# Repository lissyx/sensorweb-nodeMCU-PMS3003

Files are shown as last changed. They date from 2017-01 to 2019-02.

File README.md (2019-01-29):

NodeMCU PMS3003 PM2.5 Sensor
============================

This repo aims at providing a PM2.5 (and others) sensor that pushes data to the
Internets, namely AirCasting API. It uses a PMS3003 + NodeMCU v1.0 (ESP-12E), as
it was built as a side-project to augment (now defunct) Mozilla SensorWeb
project with something that could be autonomous and outdoor.

Good Known Setup
================
 - Arduino IDE 1.8.8
 - ESP8266 Package v2.4.2
 - ArduinoJson v5.13.5
 - NtpClientLib v2.5.1
 - Time v1.5
 - WiFiManager v0.14
 - ESP8266TrueRandom (any version?)
 - ESP8266FS.jar v0.3.0 (not a lib, need to be installed separately into tools/
   arduino subdir)

Ensure to configure board in Arduino IDE as:
 - NodeMCU 1.0 (ESP-12E)
 - 80MHz
 - Flash
 - 4M (3M SPIFFS)
 - v2 Lower Memory

Configuration
=============
For first flash, ensure you properly populate `data/` subdirectory with:
 - `wifi.json`
 - `ntp.json`
 - `aircasting.json`
Please follow the templates named <FILE>.in, copy them as the proper name under
`data/`. Then in Arduino IDE, flash using `Tools`, `ESP8266 Sketch Data Upload`.

Default configuration should be for AirCasting.org website, but it is expected
to work on any instance following their API.

Then you can build and flash. It should boot and work.

Debugging
=========
Serial debugging should work over USB. The same data is sent over the wire,
defaulting to UDP multicast address `239.0.0.1`, port `8899`.

Outdooring
==========
To be able to handle outdoor, original SensorWeb project has been augmented with
a power source. This leads to the design of a small PCB that serves several
purposes:
 - properly fitting / holding the NodeMCU with inline connectors
 - some logic to handle PMS3003 standby mode
 - proper connector for the PMS3003 wired to the NodeMCU pins
 - proper 5v: PMS3003 tends to be picky, working with less than 4v but giving
   inconsistent results

The power part of the PCB is inspired from Adafruit's Minty Boost:
https://learn.adafruit.com/minty-boost/overview

Solar power cannot be available 100% of the time, so it is battery-backed, using
the kit provided by Adafruit:
https://learn.adafruit.com/usb-dc-and-solar-lipoly-charger?view=all

Solar panel are also provided, though they can be found at a lot of different
places.

Any LiPo or LiIon should work.

Checkout the Kicad project for exact references.

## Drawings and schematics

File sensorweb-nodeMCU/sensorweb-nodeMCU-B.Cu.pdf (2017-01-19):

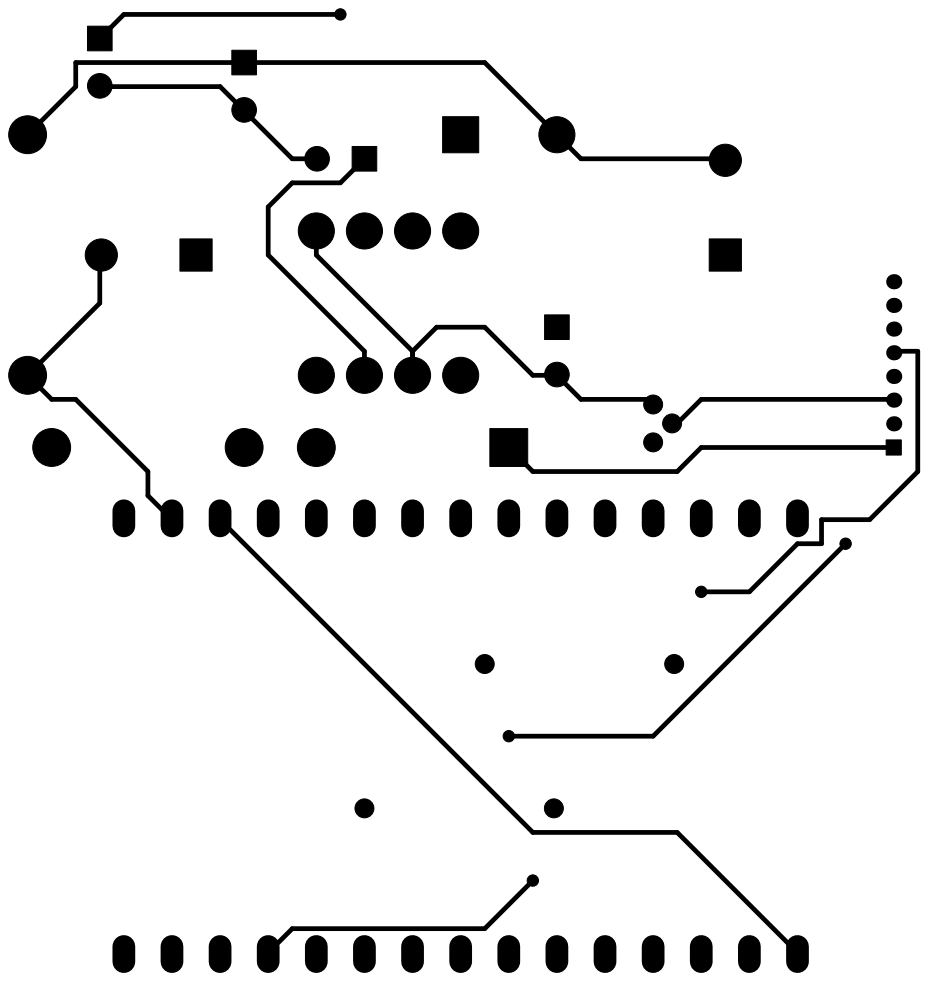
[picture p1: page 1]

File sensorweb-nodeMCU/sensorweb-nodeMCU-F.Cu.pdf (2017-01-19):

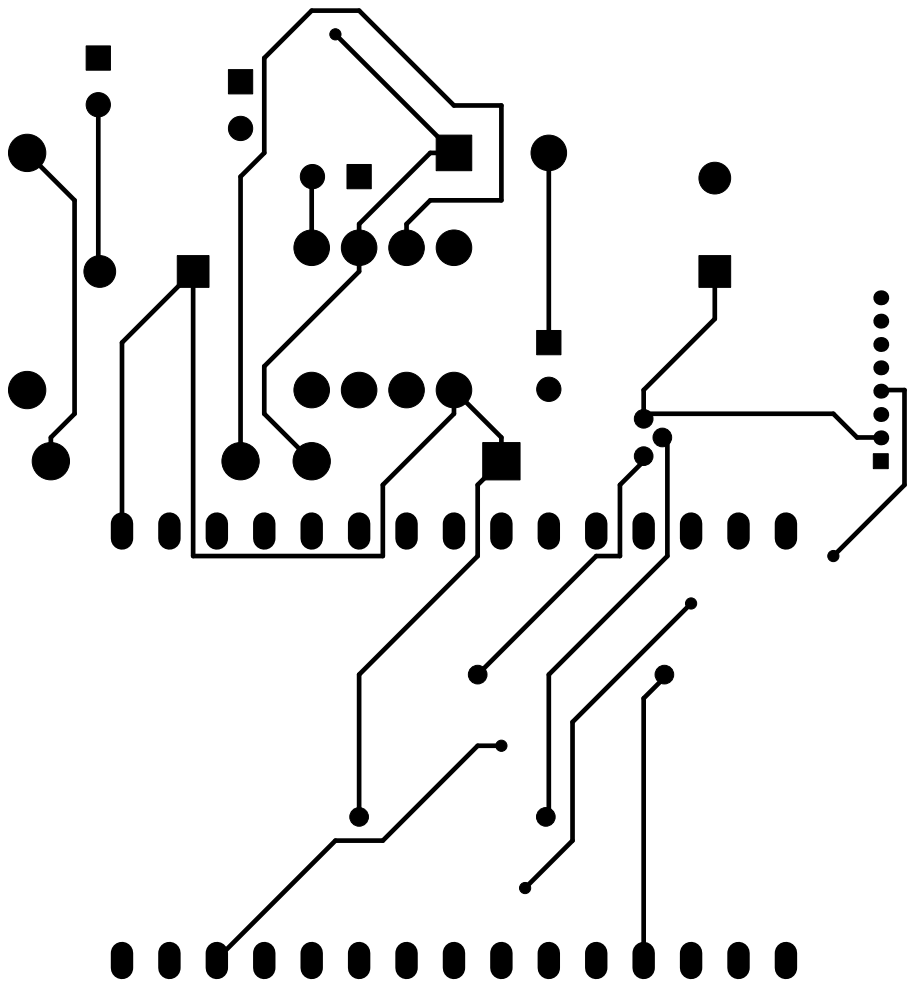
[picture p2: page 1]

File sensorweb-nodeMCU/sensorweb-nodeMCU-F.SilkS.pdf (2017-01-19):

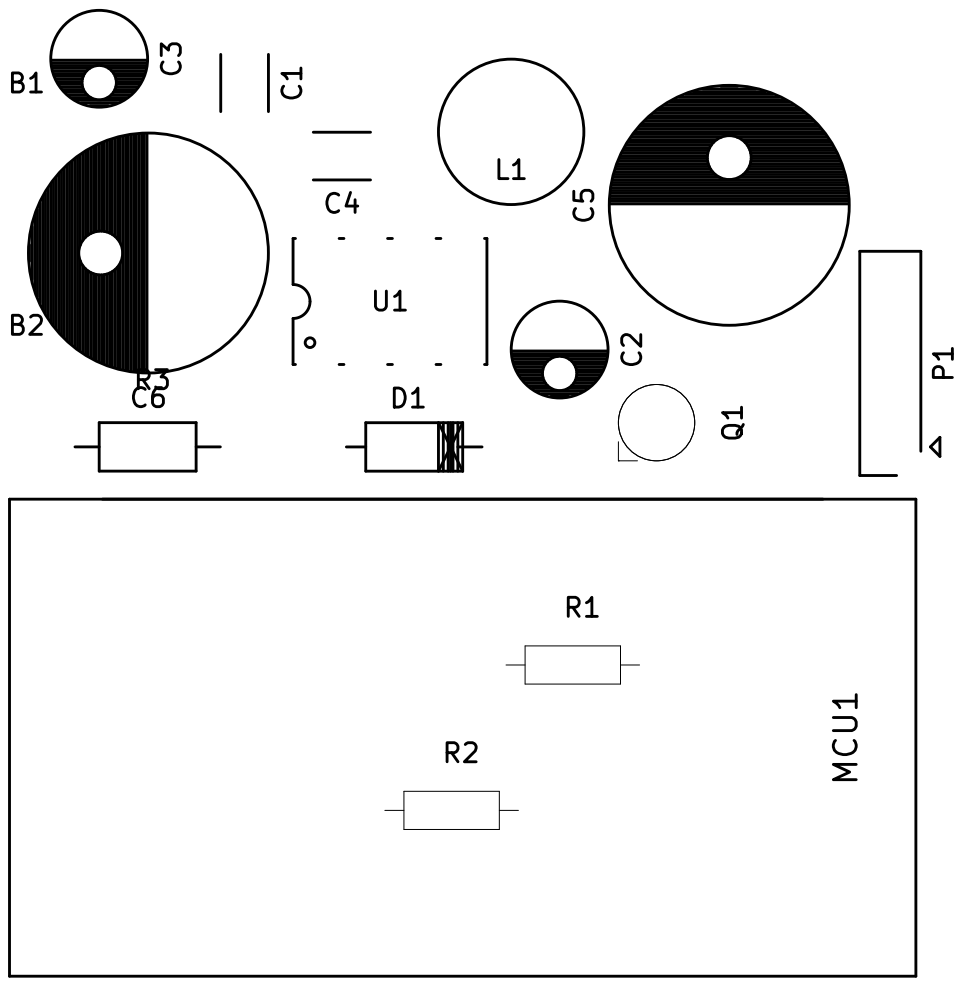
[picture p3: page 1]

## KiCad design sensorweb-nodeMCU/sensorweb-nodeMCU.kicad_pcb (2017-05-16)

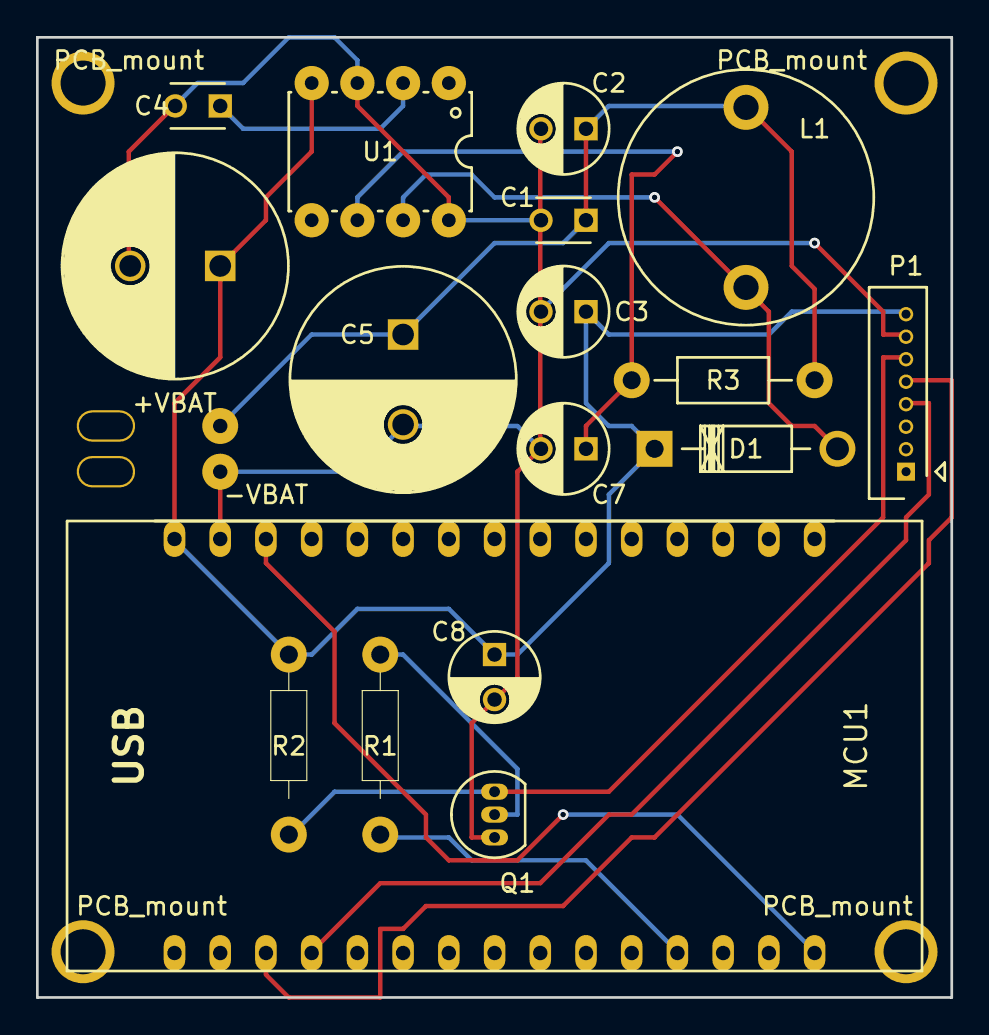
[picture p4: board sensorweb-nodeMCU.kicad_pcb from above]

Board: 2 copper layers, 50.8 x 53.3 mm, 19 parts (0 on the bottom side), 12 nets.

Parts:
+VBAT: +VBAT; SolderWirePad_single_0-8mmDrill
-VBAT: -VBAT; SolderWirePad_single_0-8mmDrill
C1, C4: 0.1µF; C_Disc_D3_P2.5
C2, C3, C8: 220µF; C_Radial_D5_L6_P2.5
C5, C6: 4700µF; C_Radial_D12.5_L25_P5
C7: 1µF; C_Radial_D5_L6_P2.5
D1: 1N5817; Diode_DO-41_SOD81_Horizontal_RM10
L1: 22µH; Neosid_Inductor_Sd14
MCU1: NodeMCU-1.0; nodemcu
P1: PMS3003; Molex_PicoBlade_53047-0810
Q1: 2N2222; TO-92_Inline_Narrow_Oval
R1, R2: 10k; Resistor_Horizontal_RM10mm
R3: 2ohm / 10ohm; Resistor_Horizontal_RM10mm
U1: LT1302CN8-5; PDIP-8

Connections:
+5V: C3.1, C6.1, C8.1, D1.1, MCU1.15, P1.8, R2.1, U1.4
GND: -VBAT.1, C1.2, C2.2, C3.2, C4.2, C5.2, C6.2, C7.2, C8.2, MCU1.14, P1.7, Q1.1, U1.3, U1.8
unnamed: +VBAT.1, C1.1, C2.1, C5.1, L1.2, R3.1
unnamed: C4.1, U1.2
unnamed: C7.1, R3.2, U1.6
unnamed: D1.2, L1.1, U1.7
unnamed: MCU1.13, MCU1.30
unnamed: MCU1.18, P1.5
unnamed: MCU1.19, P1.4
unnamed: MCU1.27, R1.2
unnamed: P1.6, Q1.3, R2.2
unnamed: Q1.2, R1.1

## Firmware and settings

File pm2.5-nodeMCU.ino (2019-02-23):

#include <Arduino.h>

#include <ESP8266WiFi.h>
#include <ESP8266WiFiMulti.h>
#include <ESP8266HTTPClient.h>

#include <ArduinoJson.h>
#include <FS.h>
#include <NtpClientLib.h>
#include <WiFiUdp.h>

uint32 pm1   = UINT32_MAX;
uint32 pm2_5 = UINT32_MAX;
uint32 pm10  = UINT32_MAX;

unsigned int sleepWakeCycles = 0;
unsigned long rtcSystemTime  = 0;
unsigned long startupMillis = 0;

#include "debug.h"
#include "config.h"
#include "LEDs.h"
#include "PMS3003.h"
// #include "SensorWeb.h"

// used by date_ISO8601() in utils.h
#include "utils.h"

#include "AirCasting.h"
#include "RTC.h"

bool ntpInitialSync = false;
bool readyForNTP = false;
bool ntpRunning = false;
unsigned int ntpErrors = 0;
double ntpStartTime = 0;
double ntpWaitTime  = 0;
ESP8266WiFiMulti* WiFiMulti;

void ntpSyncEventHandler(NTPSyncEvent_t error) {
  if (!ntpRunning) {
    serialUdpDebug("NTPSyncEvent: Ignoring stale event, expected with dayLight=true");
    /**
     * 23:07:52.019 -> NTPSyncEvent: Stale event, expected with dayLight=true
     * 23:07:52.085 -> NTPSyncEvent: 07:28:16 07/02/2036
     * 23:07:52.119 -> NTPSyncEvent: actualRuntime=2.27 -- bootTime=325
     * 23:07:52.152 -> NTPSyncEvent: actualSystemTime=2036-02-07T07:28:16.000+01:00 -- expectedSystemTime=2019-01-29T23:08:08.000+01:00
     * 23:07:52.285 -> NTPSyncEvent: deltaTime=-537178804.94200 => slowDownFactor=-1790595.01647
     */
    return;
  }

  ntpRunning = false;

  if (error) {
    ntpErrors += 1;
    if (error == noResponse) {
      serialUdpDebug("NTPSyncEvent: server not reachable");
    } else if (error == invalidAddress) {
      serialUdpDebug("NTPSyncEvent: invalid server address");
    } else {
      serialUdpDebug("NTPSyncEvent: " + String(error));
    }
  } else {
    ntpErrors = 0;
    serialUdpDebug("NTPSyncEvent: " + NTP.getTimeDateString(NTP.getLastNTPSync()));
    if (!ntpInitialSync) {
      // serialUdpDebug("NTPSyncEvent: set ntpInitialSync");
      ntpInitialSync = true;
    }

    ntpWaitTime = millis() - ntpStartTime;

    // If we receive a ntpSyncEvent for sleepWakeCycles=1 then we
    // are there to compute slowdown factor.
    if (sleepWakeCycles == sleepWakeCyclesSlowDownCompute) {
      double actualSystemTime   = NTP.getLastNTPSync();
      double actualRuntime      = getCurrentExecutionTime();
      double expectedSystemTime = rtcSystemTime + actualRuntime;
      double deltaTime = expectedSystemTime - actualSystemTime + (bootTime / 1000.0) + (ntpWaitTime / 1000.0);
      slowDownFactor = 1.0 + (deltaTime / execInterval);

      serialUdpDebug("NTPSyncEvent: actualRuntime=" + String(actualRuntime) + " -- bootTime=" + String(bootTime));
      serialUdpDebug("NTPSyncEvent: actualSystemTime=" + date_ISO8601(actualSystemTime) + " -- expectedSystemTime=" + date_ISO8601(expectedSystemTime));
      serialUdpDebug("NTPSyncEvent: deltaTime=" + String(deltaTime, 5) + " => slowDownFactor=" + String(slowDownFactor, 5));
    }
  }
}

void startNtp() {
  if (!ntpRunning) {
    ntpRunning = true;
    NtpConfig* ntpConfig = NtpConfig::getInstance();
    NTP.onNTPSyncEvent(ntpSyncEventHandler);
    NTP.begin(ntpConfig->ntpServer, ntpConfig->ntpTZOffset, ntpConfig->ntpDayLight);
    NTP.setInterval(ntpFirstSync, ntpInterval);
    serialUdpIntDebug("NTP: NTP.begin(" + ntpConfig->ntpServer + ", " + ntpConfig->ntpTZOffset + ", " + ntpConfig->ntpDayLight + ")");
    ntpStartTime = millis();
  } else {
    serialUdpIntDebug("NTP: not starting because ntpRunning=true");
  }
}

void stopNtp() {
  ntpRunning = false;
  NTP.stop();
}

void wifiHasIpAddress(WiFiEventStationModeGotIP evt) {
  serialUdpIntDebug("UP: " + VERSION + ":" + (BUILD_DATE + " " + BUILD_TIME) + "@" + evt.ip.toString());

  // Only schedule NTP sync when we do need it.
  if (sleepWakeCycles <= sleepWakeCyclesSlowDownCompute) {
    readyForNTP = true;
  }
}

void wifiConnected(WiFiEventStationModeConnected evt) {
  serialUdpIntDebug("Connected to SSID: " + evt.ssid);
}

void wifiDisconnected(WiFiEventStationModeDisconnected evt) {
  DEBUG_SERIAL("Disconnected from SSID: " + evt.ssid + "; reason: " + evt.reason);
  DEBUG_SERIAL("Reason: " + evt.reason);

  readyForNTP = false;

  if (sleepWakeCycles <= sleepWakeCyclesSlowDownCompute) {
    stopNtp();
  }
}

void setup() {
  static WiFiEventHandler connectEvent, hasIpEvent, disconnectEvent;

  startupMillis = millis();

  WiFi.persistent(true);
  WiFi.mode(WIFI_STA);

  // Measure how much power we can save there ...
  // According to ESP docs:
  // 802.11b: TX ~170mA, RX ~50mA
  // 802.11g: TX ~140mA, RX ~56mA
  // 802.11n: TX ~120mA, RX ~56mA
  WiFi.setPhyMode(WIFI_PHY_MODE_11N);

  const rst_info * resetInfo = system_get_rst_info();
  if (resetInfo->reason == REASON_DEEP_SLEEP_AWAKE) {
    if (readTimeFromRTC()) {
      // If we wake up from deep sleep AND sleepWakeCycles is one
      // it means we did a first NTP sync. Let's do a second one.
      if (sleepWakeCycles < forceResync) {
        if (sleepWakeCycles > sleepWakeCyclesSlowDownCompute) {
          ntpInitialSync  = true;
        }
      } else {
        sleepWakeCycles = 0;
        slowDownFactor  = 1.0;
      }
    }
  }

  // Reconfigure watchdog at least twice expected secs.
  ESP.wdtEnable(30 * 1000);

  PM_SERIAL.begin(9600);
  DEBUG_SERIAL("Booting ...");

#if LWIP_IPV6
  DEBUG_SERIAL("IPV6 is enabled\n");
#else
  DEBUG_SERIAL("IPV6 is not enabled\n");
#endif

  configure_leds();
  configure_pms3003_pin();

  // put PMS3003 into standby for now
  power_pms3003(false);

  hasIpEvent      = WiFi.onStationModeGotIP(wifiHasIpAddress);
  connectEvent    = WiFi.onStationModeConnected(wifiConnected);
  disconnectEvent = WiFi.onStationModeDisconnected(wifiDisconnected);

  ntpRunning = false;
  NTP.stop();

  WiFiMulti = new ESP8266WiFiMulti();
  WifiConfig wifiConfig;
  for(int itCreds = 0 ; itCreds < wifiConfig.creds.size(); itCreds++ ) {
    WifiCreds c = wifiConfig.creds[itCreds];
    if (c.pass().length() > 0) {
      WiFiMulti->addAP(c.ssid().c_str(), c.pass().c_str());
      DEBUG_SERIAL("WifiConfig: Adding WiFi for protected " + c.ssid());
    } else {
      WiFiMulti->addAP(c.ssid().c_str());
      DEBUG_SERIAL("WifiConfig: Adding WiFi for open " + c.ssid());
    }
  }

  BLINK_LED_BOOT;
}

void loop() {
  // Let's take a few (extra) seconds and make sure brand new devices can connect.
  // Doing that always will cripple boot time:
  //  - with WiFiMulti->run() checking, we get IP ~7 secs after boot
  //  - without, we get IP ~2.9 secs after boot
  if (sleepWakeCycles == 0) {
    if (WiFiMulti->run() != WL_CONNECTED) {
      DEBUG_SERIAL("WifiConfig: not connected, waiting ...");
      delay(500);
      return;
    }
  }

  if (readyForNTP) {
    startNtp();
  }

  // Wait for NTP sync at least 3*45 secs
  // If we get nothing, go to sleep. Let's hope it is a transient issue.
  String timeNow = date_ISO8601(now(), false, false);
  if (!ntpInitialSync && (ntpErrors < 3)) {
    serialUdpDebug("Loop: no NTP initial sync, waiting ... sleepWakeCycles=" + String(sleepWakeCycles) + " ntpErrors=" + String(ntpErrors));
    delay(1250);
    return;
  }

  // Do not try to collect or send data if we have not received any NTP sync event.
  if (ntpErrors < 3) {
    AirCasting ac;
    String sessionUUID = ac.getSessionUUID();

    serialUdpDebug("SessionUUID: " + sessionUUID);
    serialUdpDebug("NTP: " + timeNow);

    // Read values from the PMS3003 connected sensor
    collect_pms3003_sensor();

    // Send even if value is 0 ; it just means sensor detected nothing.
    if(pm2_5 < UINT32_MAX && sessionUUID.length() > 0) {
      bool sent = ac.push(timeNow, pm2_5);
      serialUdpDebug("NTP: " + timeNow + " PM2.5: " + String(pm2_5) + " UUID:" + sessionUUID + " sent:" + sent);
    }
  } else {
    serialUdpDebug("Loop: too many NTP errors. Aborting.");
  }

  double executionTime = getCurrentExecutionTime();
  double nextInterval  = ((double)execInterval - (double)executionTime) * 1.0;

  // Ensure that we have something within range of [1; execInterval]
  nextInterval = MAX(1, MIN(nextInterval, execInterval));

  serialUdpDebug("Loop: deepSleep: nextInterval=" + String(nextInterval) +
                 "; executionTime=" + String(executionTime) +
                 " ; slowDownFactor=" + String(slowDownFactor, 5) +
                 "; deepSleep(" + String(nextInterval * slowDownFactor) + ")");

  // Write time to RTC only if we could get some valid.
  // e.g., no ntp works during first boot of the system
  // then goes to sleep writing time to RTC
  // When it wakes up it would restore time as if it was good
  // => you end up in the 1970s
  if (ntpInitialSync) {
    writeTimeToRTC(now(), nextInterval);
  }

  // with WAKE_RF_DEFAULT, deep sleep current ~8.2mA
  // with WAKE_NO_RFCAL, deep sleep current ~8.2mA
  // with WAKE_RF_DISABLED, no wifi on return from sleep, and deep sleep current ~8.2mA
  ESP.deepSleep(nextInterval * slowDownFactor * 1e6, WAKE_NO_RFCAL);

  return;
}

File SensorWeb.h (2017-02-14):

#ifndef PM25_NODEMCU_SENSORWEB_H
#define PM25_NODEMCU_SENSORWEB_H

/*
String jsonToString(JsonObject& obj) {
  const unsigned int MAX_JSON = sizeof(char) * 2048;
  char* jsonChar = (char *)malloc(MAX_JSON);
  if (!jsonChar) {
    free(jsonChar);
    serialUdpDebug("Cannot allocate memory");
    return "";
  }

  obj.printTo(jsonChar, MAX_JSON);
  String rv(jsonChar);
  free(jsonChar);

  return rv;
}
*/

String extractJsonField(String field, String httpPayload) {
  DynamicJsonBuffer jsonReceiveBuffer;
  JsonObject& replyRoot = jsonReceiveBuffer.parseObject(httpPayload.c_str());

  if (!replyRoot.success()) {
    serialUdpDebug("JSON: Parsing failure");
    return "";
  }

  if (!replyRoot.containsKey(field)) {
    serialUdpDebug("JSON: No field named " + field + " in reply");
    return "";
  }

  return replyRoot.get<String>(field);
}

String extractIotId(String httpPayload) {
  return extractJsonField("@iot.id", httpPayload);
}

String extractErrno(String httpPayload) {
  return extractJsonField("errno", httpPayload);
}

String extractErrMsg(String httpPayload) {
  return extractJsonField("error", httpPayload);
}

String getDataStream() {
  DynamicJsonBuffer jsonSendBuffer;
  JsonObject& root              = jsonSendBuffer.createObject();

  JsonObject& unitOfMeasurement = root.createNestedObject("unitOfMeasurement");
  unitOfMeasurement["symbol"]     = "μg/m³";
  unitOfMeasurement["name"]       = "PM 2.5 Particulates (ug/m3)";
  unitOfMeasurement["definition"] = "http://unitsofmeasure.org/ucum.html";

  root["observationType"] = "http://www.opengis.net/def/observationType/OGC-OM/2.0/OM_Measurement";
  root["description"]     = "Air quality readings";
  root["name"]            = "air_quality_readings";

  JsonObject& Thing = root.createNestedObject("Thing");
  Thing["description"] = "A SensorWeb Thing";
  Thing["name"]        = "SensorWebThing";
  JsonObject& ThingProperties = Thing.createNestedObject("properties");
  ThingProperties["organization"] = "Mozilla";
  ThingProperties["owner"]        = "Mozilla";
  JsonArray& ThingLocations  = Thing.createNestedArray("Locations");
  JsonObject& MyLocation     = ThingLocations.createNestedObject();
  MyLocation["description"]  = "My Location Description";
  MyLocation["name"]         = "My Location Name";
  MyLocation["encodingType"] = "application/vnd.geo+json";
  JsonObject& Location       = MyLocation.createNestedObject("location");
  Location["type"]           = "Point";
  JsonArray& LocationCoordinates = Location.createNestedArray("coordinates");
  LocationCoordinates.add(SensorWebConfig::getInstance()->coordinates[0], 6);
  LocationCoordinates.add(SensorWebConfig::getInstance()->coordinates[1], 6);

  JsonObject& ObservedProperty = root.createNestedObject("ObservedProperty");
  ObservedProperty["name"]        = "PM 2.5";
  ObservedProperty["description"] = "Particle pollution, also called particulate matter or PM, is a mixture of solids and liquid droplets floating in the air.";
  ObservedProperty["definition"]  = "https://airnow.gov/index.cfm?action=aqibasics.particle";

  JsonObject& Sensor = root.createNestedObject("Sensor");
  Sensor["description"]  = "PM 2.5 sensor";
  Sensor["name"]         = "PM25sensor";
  Sensor["encodingType"] = "application/pdf";
  Sensor["metadata"]     = "http://particle-sensor.com/";

  String jsonPayload; root.printTo(jsonPayload);
  serialUdpDebug("JSON: " + jsonPayload);

  HTTPClient http;
  http.begin(SensorWebConfig::getInstance()->apiDatastreams, SensorWebConfig::getInstance()->apiFingerprint);
  http.addHeader("Cache-Control", "no-cache");
  http.addHeader("Content-Type", "application/json");
  http.addHeader("Connection", "close");
  int rc = http.POST(jsonPayload);

  serialUdpDebug("HTTP:DS: Code " + String(rc));
  if (rc > 0) {
    if (rc == HTTP_CODE_OK || rc == HTTP_CODE_CREATED) {
      String payload = http.getString();
      serialUdpDebug("HTTP:DS: OK");
      serialUdpDebug("HTTP:DS: REPLY: " + payload);

      String iotId = extractIotId(payload);
      serialUdpDebug("HTTP:DS: @iot.id: " + iotId);
      return iotId;
    }
  }

  return "";
}

String pushObservation(String iotId, String date, unsigned int pm2_5) {
  DynamicJsonBuffer jsonSendBuffer;
  JsonObject& root       = jsonSendBuffer.createObject();
  root["phenomenonTime"] = date;
  root["resultTime"]     = date;
  root["result"]         = String(pm2_5); // Make it a string after API change broke it as an int.

/*
 * We can rely on auto-creation of FeatureOfInterest
 * 
  JsonObject& FeatureOfInterest = root.createNestedObject("FeatureOfInterest");
  FeatureOfInterest["name"]         = "PM2.5 Tours";
  FeatureOfInterest["description"]  = "PM2.5 Sensor in Tours";
  FeatureOfInterest["encodingType"] = "application/vnd.geo+json";
  JsonObject& Feature       = FeatureOfInterest.createNestedObject("feature");
  Feature["type"]           = "Point";
  JsonArray& FeatureCoordinates = Feature.createNestedArray("coordinates");
  FeatureCoordinates.add(SensorWebConfig::getInstance()->coordinates[0], 6);
  FeatureCoordinates.add(SensorWebConfig::getInstance()->coordinates[1], 6);
*/

  JsonObject& Datastream = root.createNestedObject("Datastream");
  Datastream["@iot.id"]  = iotId;

  String jsonPayload; root.printTo(jsonPayload);
  serialUdpDebug("JSON: " + jsonPayload);

  HTTPClient http;
  http.begin(SensorWebConfig::getInstance()->apiObservations, SensorWebConfig::getInstance()->apiFingerprint);
  http.addHeader("Cache-Control", "no-cache");
  http.addHeader("Content-Type", "application/json");
  http.addHeader("Connection", "close");
  int rc = http.POST(jsonPayload);

  String payload = http.getString();
  serialUdpDebug("HTTP:OS: REPLY: " + payload);

  // Pushing observation will return successfull 200/201 when it is okay.
  // If IotID is invalid, we get HTTP status 400 and error errno 102
  serialUdpDebug("HTTP:OS: Code " + String(rc));
  if (rc > 0) {
    if (rc == HTTP_CODE_OK || rc == HTTP_CODE_CREATED) {
      BLINK_LED_PUSH_OK;
      serialUdpDebug("HTTP:OS: OK");
      
      String replyIotId = extractIotId(payload);
      serialUdpDebug("HTTP:OS: @iot.id: " + replyIotId);
      return replyIotId;
    }
  } else {
    String _error = extractErrMsg(payload);
    String _errno = extractErrno(payload);
    serialUdpDebug("HTTP:OS: Code " + String(rc) + " (" + http.errorToString(rc) + ") " + " with errno=" + _errno + ": '" + _error + "'");
  }
  // TODO: Handle error code, if errno 102 "Invalid association. Datastream with id X not found", then
  // remove iotid file and restart the sensor.
}
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

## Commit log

2017-01-19 First commit with something somehow working.
    [sensorweb-nodeMCU.kicad_pcb, sensorweb-nodeMCU.sch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]
2017-01-27 Improve HTTP error reporting
    [SensorWeb.h]
2017-02-14 Switching to AirCasting.org
2017-02-14 Send device hostname with UDP debug message
2017-02-14 Distinguish session per sensor
2017-03-19 Update schematics
2017-05-16 Fixing schematic and PCB
    [sensorweb-nodeMCU.kicad_pcb, sensorweb-nodeMCU.sch]
2018-01-04 Force WiFi to 802.11n to reduce power pressure.
2019-01-29 Fix crash with NtpClientLib v2.5.x and get lwIP variant v2
    [pm2.5-nodeMCU.ino]
2019-02-21 Fix bogus field triggering HTTP/500 with new Rails version
2019-02-23 Fix error 500 when sending measurements after rails upgrade
    [pm2.5-nodeMCU.ino, utils.h]
